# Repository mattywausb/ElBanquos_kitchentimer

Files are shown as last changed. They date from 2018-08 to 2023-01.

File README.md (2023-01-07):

# ElBanquos Kitchentimer
An Arduino based "multichannel" Timer, optimized for tracking times during food preparation

# Motivation
When preparing food I have to keep track of multiple countdowns. Even though one could solve this by putting multiple cheap timers on the fridge door or use a smartphone app there are some benefits with an extra device.
* better control when setting the time (cheap timers normally just go up, higher settings are a pain, correcting after start is nearly impossible)
* no need to clean all your fingers to change a timer
* Smartphone normally switches of the screen, so you can't see the current state (or they keep screen on and drain smart phone battery for neraly nothing)
* Smartphone somtimes is needed to check recepies, problem solutions or communicating (is that so?). Again you cannot see the current state of the timers just by looking at the device

# Features
* Track up to 4 timers (Well... limited by the number of display and interaction elements, you can extend this, with little modification)
* Main display mode shows all timers (no need to push a button to see the timers)
* wide range of intervals (1 second to 6 days (and thats only a coded limit) )
* Interval presets for your major use cases
* Assistence to set timer in relation to other timer
* Identity of alarming timer is "coded" in alarm melody

## Easy and intuitive 2 finger operations
* Set and start timer
* Size of dial steps adapts to total interval (there is normally no need to scroll over every second, when the interval is more than 5 minutes)
* Acknowledge alarm
* Change an alreday running timer (necessary when something irregular happened in the cooking process)
* put timer on hold
* cancel timer
* check the original time, the timer started from
* measure time since timer is over
  
# What you will find in the repository
* Arduino sketch for the timer
* Fritzing sketch for the hardware used in the implementation
* Manuals
    * [English](https://mattywausb.github.io/ElBanquos_kitchentimer/docs/manual-en.html)
    * [German](https://mattywausb.github.io/ElBanquos_kitchentimer/docs/manual-de.html)

# What you also need
* my extended version of the arduino "ledcontrol" library: https://github.com/mattywausb/LedControl

# How can you use it
* You can just build the timer by yourself using the same parts (check the fritzing sketch)
* The module architecture allows you to excahnge the elements of the interface
  * Display type
  * Kind of buttons input methods
  * sound generation
  
# Video
* [Demo and quick guide video](https://youtu.be/dwYkCimMoDo)

# More details 
* [check the wiki] (https://github.com/mattywausb/ElBanquos_kitchentimer/wiki)

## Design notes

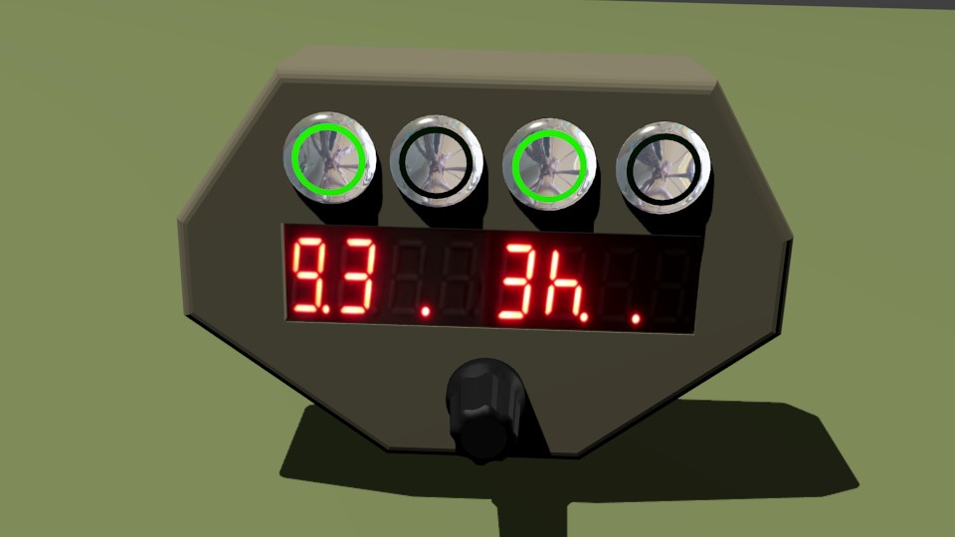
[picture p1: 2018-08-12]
docs/vision_1.jpg

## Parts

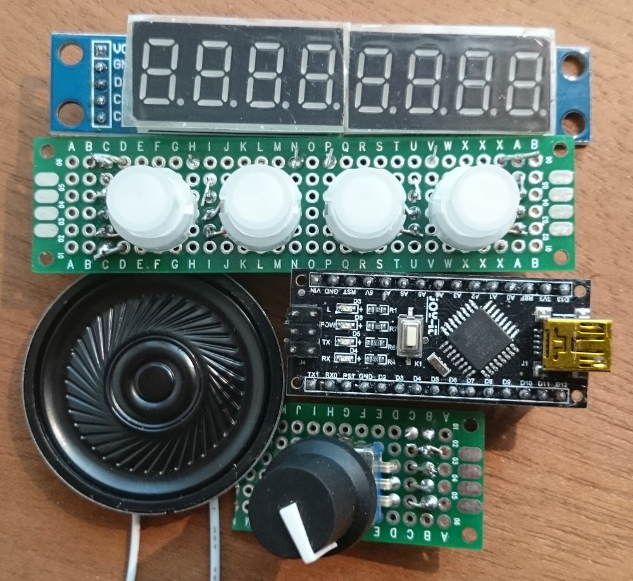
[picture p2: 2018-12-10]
docs/build_pictures/01_components_front.jpg

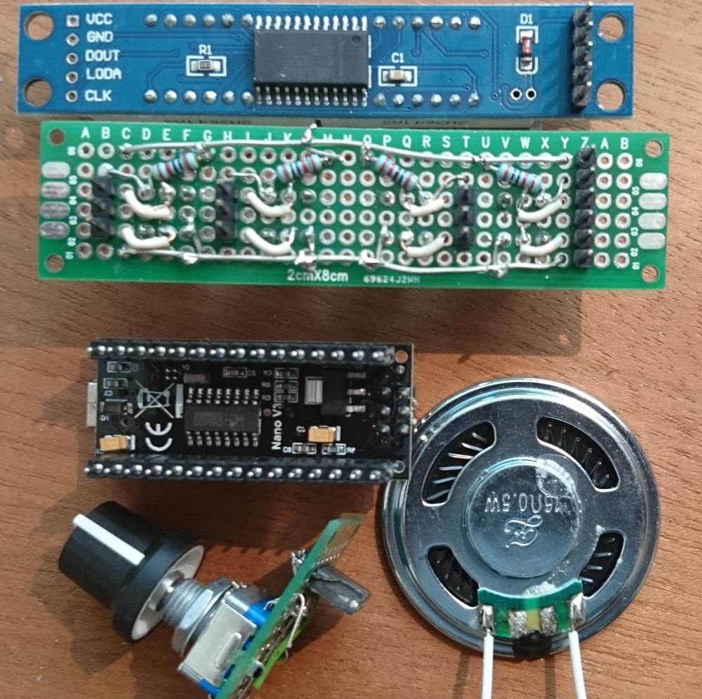
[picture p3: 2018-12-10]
docs/build_pictures/02_components_rear.jpg

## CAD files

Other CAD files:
blender/model_mk2.blend

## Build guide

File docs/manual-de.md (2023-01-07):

[Back to mainpage](https://mattywausb.github.io/ElBanquos_kitchentimer)
___
# Elemente und Aufbau des Gerätes
Elbanquos Kitchentimer besteht aus folgenden Elementen:
* 8 stellige Ziffenanzeige, je nach Modus 2 Ziffern zu jedem Timer oder für 8 stelliges Informationen 
* Je Timer ein dedizierter Taster
* Je Timer eine Timer-LED (eingebaut in den Taster)
* Zentraler Drehregler mit Tastfunktion

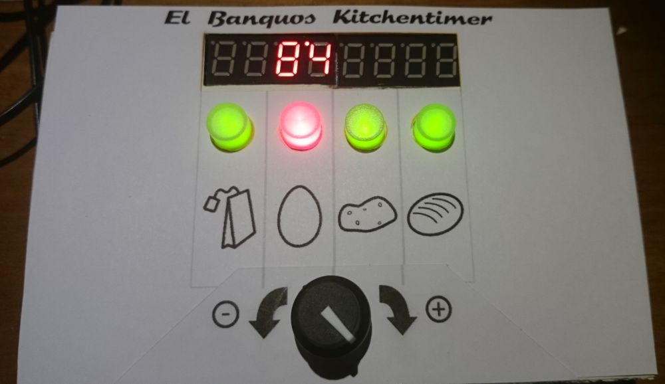
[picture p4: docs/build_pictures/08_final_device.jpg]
The timer


# Kurzanleitung
Um einen Timer zu **aktivieren** ist folgendes zu tun
* Mit dem  ***Drehregler*** die gewünschte Zeit einstellen (beginnt bei **10 Minuten**)
* Taster eines inaktiven (LED Grün oder aus) Timers drücken ->  Der Timer startet. Der Timer Taster leuchtet dauerhaft rot.

Um einen **Timer mit einer voreingestellte Zeit** zu aktivieren:
* ***Taster*** des gewünschten Timers ***drücken*** -> die Vorgabezeit des jeweiligen Timers wird angezeigt und der Taster blinkt grün
* Mit dem ***Drehregler*** bei Bedarf die Zeit anpassen
* Um die Zeit ggf. auf einem anderen freien Timer zu legen, ***anderen Timer Taster drücken***
* ***Taster des Timers oder den Drehregler drücken*** -> Der Timer startet. Der Timer Taster leuchtet dauerhaft rot.

Um bei einem aktiven Timer die **verbleibende Zeit exakt abzulesen**:
* ***Taster des gewünschten Timers drücken*** -> Zeit wird in allen Details angezeigt
* ***Taster des Timers erneut drücken*** -> es werden wieder alle Timer angezeigt

Um die Zeit eines bereits **laufenden Timers zu ändern**:
* ***Taster des gewünschten Timers drücken*** -> Zeit wird in allen Details angezeigt
* Mit dem ***Drehregler*** die Zeit anpassen
* ***Taster des Timers*** drücken ***oder den Drehregler kurz drücken***

Ist ein **Timer abgelaufen** ertönt ein Signalton und Taster und Anzeige des Timers blinken sehr schnell.
* **Alarm beenden** Durch ***drücken des blinkenden Tasters***
* Alternativ schaltet sich der Alarm nach 45 Sekunden von selbst ab sofern nicht ein weitere Timer abläuft. 

Im **Nachlaufmodus** zählt der Timer die Zeit, die mit Beginn des Alarms verstrichen ist. Der Timer-Taster ist dunkel und im Display wird die seit dem Alarm verstrichene Zeit abwechselnd mit "\_ \_" angezeigt. Ab 2 Minuten wird nur noch "\_ \_" angezeigt. Die **seit dem Alarm verstrichende Zeit** kann durch ***Drücken des Tasters*** abgerufen werden. 

Um einen Timer (egal ob abgelaufen oder aktiv) zu **deaktivieren** ist folgendes zu tun:
* ***Taster des Timers 5 Sekunden halten*** -> Für den Timer wird kurz "OF angezeigt und der Timer ist danach wieder inaktiv (grün). Ein abgelaufender Timer deaktiviert sich selbst nach der Hälfte seiner ursprünglichen Laufzeit. (Frühestens allerding nach 3 Minuten und spätestens nach 90 Minuten)

Weitere Funktionen werden im Abschnitt "Die Fuktionen im einzelnen" beschrieben.

# Die Zeitanzeige im Detail
## Hauptanzeige (Kompakte Darstellung aller Timer parallel)
Auf der Hauptanzeige werden die Zeiten von allen Timern parallel nebeneinander dargestellt. Für jeden Timer sind zwei Ziffern der Anzeige passend zur Position des Tasters und der Timer-Led vorgesehen. Die Darstellung ist wie folgt:
* **Zeitinformation**
    * "zz" (Zwei Ziffern, ohne Punkt, sekündlich abwärtslaufend) - verbleibende Sekunden zz bis zum Alarm 
    * "y'z" (Zwei Ziffern, mit einem Punkt oben getrennt) - mehr als 60 Sekunden Zeit: Vor dem Punkt : Verbleibende Minuten y, Nach dem Punk verbeibende 10 Sekundenschritte
    * "'yy" (Zwei Ziffern, denen ein Punkt vorangestellt ist) - mehr als 10 Minuten Zeit: Verbleibende Minuten
    * "xh" - (eine Ziffer gefolgt von einem kleinen h und einem Punkt) -  mehr als 1 Stunde Zeit: Verbleibende Stunden x
    * "Hx'" - (Ein großes H gefolgt von einer Ziffer und einem Punkt) -  mehr als 10 Stunden Zeit: Verbleibende 10 Stundenschritte
    * "vd'" - (eine Ziffer gefolgt von einem d und einem Punkt) -  mehr als 24 Stunden Zeit: verbleibende Tage
* **Statusinformation**
	* keine Anzeige - Der Timer ist nicht aktiv
    * "\_ \_"  = Der Timer ist im Nachlaufmodus
    * "\_ \_"  Wechselnd zu einer der Zeitinformation = Der Alarm ist keine 2 Minuten her
    * "°_" und "_°" = Timer Alarm in schnellem Wechsel mit einer Zeitinformation
	* "P" vor der Zeitanzeige: Die Zeiteinstellung erfolgt in Relation zu einem Partnertimer
	* "A" vor der Zeitanzeige: Es wird die ursprünglich eingestellte Zeit des Timers angezeigt

Beispiele:
* 12 = 12 Sekunden 
* 5'3 = 5 Minuten und 30-39 Sekunden
* 24' = 24 Minuten
* 2h  = Zwischen 2 Stunden und 2 Stunden, 59 Minuten, 59 Sekunden
* 4d  = Mindestenst 4 Tage, weniger als 5 Tage

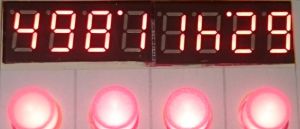
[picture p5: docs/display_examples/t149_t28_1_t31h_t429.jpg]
Example


* Timer 1 hat noch 49 Sekunden
* Timer 2 hat noch 8 Minuten und mindestens 10 Sekunden
* Timer 3 hat noch mehr als 1 Stunde (aber weniger als 2)
* Timer 4 hat noch 29 Minuten
 
## Anzeige einer einzelnen Zeit
Bei der Auswahl eines Timers und für die Einstellung der Zeit gibt zwei Formate der Darstellung:

* xx**h**'yy'zz - Für alle Werte unter 24 Stunden wird die Stunde x, die Minuten yy und die Sekunden zz angezeigt
* v**d**xx**h**'yy - Wert größer 24 Stunden werden mit der Anzahl Tage v, die Stunden xx und Minuten yy angezeigt.

Beispiel:
Example

## Information durch die LED im Timer-Taster
* LED **grün** durchgehend: Der Timer ist ***inaktiv*** 
* LED **blinkt regelmäßig**: Der Timer ist ***ausgewählt*** für die Detailsanzeige oder Zeiteinstellung. Sollten zwei Timer blinken, so wird der grün blinkende Timer in Relation zu dem rot blinkenden eingestellt. 
* LED **rot** durchgehend: Der Timer ***läuft***
* LED **rot schnell blinkend** mit kurzen Pausen: Der Timer hat einen ***Alarm***
* LED **rot** erlischt kurz im **"Herzschlagryhtmus"**: Der Timer ist im ***Pausemodus***
* LED **aus**: Der Alarm für den Timer wurde beendet und der Timer ist im ***Nachlaufmodus***. Er steht für einen neuen Start zur Verfügung. 

# Die Funktionen im Einzelnen
Alle Funktionen werden hier ausgehend von der Hauptanzeige(siehe oben) beschrieben. Diese erreicht man im Zweifelsfall immer durch kurzes Warten (15 Sekunden).

## Timer einstellen und starten
Anmerkung vorab: Um auch große Zeitintervalle effizient erreichen zu können wächst der Zeitabstand pro Schritt des Drehregles mit der insgesamt gewählten Zeit. Dadurch kann nicht für jedes Intervall eine sekundengenaue Einstellung erfolgen (Weitere Details dazu im Anhang "Stufung der Einstellintervalle"). 

### Per Drehregler
* Mit dem Drehregler eine Zeit einstellen (Die erste Bewegung des Reglers setzt diese auf 10 Minuten).
* Taster eines nicht laufenden Timers (_LED grün oder aus_) drücken -> Der Timer wird gestartet.

Solange noch kein Timer ausgewählt wurde, kann die Eingabe durch langes Drücken des Drehreglers abgebrochen werden. 
Die Eingabe wird ebenfalls abgebrochen, wenn man 15 Sekunden lang keine Bedienhandlung vornimmt.

### Direkte Zeitvorwahl je Timer
* Taster eines deaktivierten(LED ist grün) Timers drücken -> die für den Timer vorprogrammierte Vorschlagszeit erscheint,Timer-Led blinkt
* Mit dem Drehregler die Zeit anpassen
* Timer starten indem man auf den Drehregler drückt _oder_ erneut die Taste des Timers betätigt
* Option: Drückt man stattdessen die Taste eines anderen inaktiven Timers, wird auf diesen als Ziel für die eingestellte Zeit umgeschaltet. Ein erneuter Druck auf dessen Taster oder den Drehknopf startet diesen Timer. Der ursprüngich ausgewählte Timer bleibt dann unberührt.

Die Eingabe durch langes drücken des Drehreglers abgebrochen werden. 
Die Eingabe wird ebenfalls abgebrochen, wenn man 15 Sekunden keine Bedienhandlung vornimmt.

### Zeitvorwahl mit abgelaufenem Timer
* Taster eines nachlaufenden(LED ist aus) Timers drücken -> die Nachlaufzeit des Timers wird angezeigt,Timer-Led blinkt
* Die erste Bewegung des Drehreglers stellt die Zeit auf die vorprogrammierte Vorschlagszeit
* Danach kann die Zeit weiter angepasst werden
* Timer starten indem man auf den Drehregler drückt _oder_ erneut die Taste des Timers betätigt
* Option:Drückt man stattdessen die Taste eines anderen inaktiven Timers, wird auf diesen als Ziel für die eingestellte Zeit umgeschaltet. Ein erneuter Druck auf dessen Taster oder den Drehknopf startet diesen Timer. Der ursprüngich ausgewählte Timer bleibt dann unberührt.

### Zeitabstand zu laufendem Timer
Möchte man einen Timer stellen, der eine definierte Zeit __vor__ einem schon laufenden Timer abläuft, ist wie folgt zu verfahren:
* Taster des aktiven Timers, für zu dem man einen Abstand festlegen will drücken und halten. 
* zusätzlich Taster des inaktiven Timers drücken, der vor dem schon aktiven Timer ablaufen soll -> Der Taster des aktiven Timers blinkt rot, der Taster des einzustellenden Tasters blinkt grün. In der Zeitanzeige wird die Hälfte der Restzeit des aktiven Timers vorgeschlagen. Mit einem "P" in der Anzeige wird angezeigt, dass der "Partnermodus" aktiviert ist
* Mit dem Drehregler die Restzeit einstellen, die der aktive Timer haben soll, wenn der jetzt eingestellte Timer abläuft.
* Den zweiten Timer starten, indem man den Drehregler drückt oder den Taster des zweiten Timers->Der zweiten Timer erhält dabei eine Laufzeit, die in Relation zu dem partner mit dem eingestellten Abstand abläuft. 
Sollte die Zeit des Ursprungstimers nicht mehr ausreichen, um die gewünschte Zeit zu realisieren, wird der Timer nicht gestartet. Stattdessen wird kurz ein Fehler angezeigt und danach die Ursprungtimer wieder angezeigt. So kann bei Bedarf, dessen Zeit veändert werden, oder das Prozedere für einen zweiten Timer erneut begonnen werden.

Die Timer sind danach nicht weiter verkoppelt, d.h. wenn der erste Timer pausiert oder verändert wird, hat das keine Auswirkung auf den zweiten Timer. Der ürsprünglich gewünschte Zeitabstand ist dann nicht mehr gegeben.

## Timer Restzeit anzeigen
Um die exakte Restzeit eines Timers anzuzeigen:
* Taster des gewünschten aktiven Timers drücken -> Ausführliche Restzeit (oder die Zeit seit dessen Ablauf) wird angezeigt. Die Timer-Led blinkt.
* Durch erneutes Drücken des Tasters wird wieder die Hauptanzeige angezeigt
* Alternativ: Durch Drücken des Tasters eines anderes aktiven Timers wird zu dessen Anzeige umgeschaltet.

## Timer pausieren
Um einen Timer anzuhalten:
* Taster des gewünschten laufenden Timers drücken -> Ausführliche Restzeit wird angezeigt. Die Timer-Led blinkt.
* Den Drehregler kurz drücken -> Auf der Position des Timers wird kurz "PA" angezeigt. Danach erscheint die Hauptanzeige und die Ziffern des Timers, sowie dessen Timer-Led blinken mit einem langsamen "Herzschlagryhtmus"

## Pausierten Timer wieder aktivieren
Um einen pausierten Timer wieder zu aktivieren:
* Taster des pausierten Timers drücken -> Ausführliche Restzeit  wird angezeigt. Die Timer-Led blinkt.
* Den Drehregler kurz drücken -> Auf der Positin des Timers wird kurz "Go" angzeigt. Danach der erscheint die Hauptanzeige und der Timer wird wieder durchgehend angezeigt.

## Timer Restzeit ändern
Um die Restzeit eines Timers anzupassen:
* Taster des gewünschten laufenden Timers drücken -> Ausführliche Restzeit (oder die Zeit seit dessen Ablauf) wird angezeigt. Die Timer-Led blinkt.
* Mit dem Drehregler die Zeit entsprechend anpassen 
* Neue Zeit mit Druck auf Drehregler oder den Taster des Timers bestätigen-> Hauptanzeige mit der geänderten Zeit wird angezeigt. War der Timer vorher pausiert, ist er jetzt wieder aktiv 
* Alternativ: Änderung durch Drücken und halten des Drehreglers verwerfen

## Timer Startzeit anzeigen
Um die ursprüngliche Startzeit des Timers anzuzeigen:
* Taster des gewünschten aktiven Timers drücken -> Ausführliche Restzeit (oder die Zeit seit nach dessen Ablauf) wird angezeigt. Die Timer-Led blinkt.
* Drehregler drücken und halten -> Die ursprüngliche Startzeit wird angezeigt bis man den Drehregler wieder loslässt
* Taster des Timers erneut drücken um wieder in die Anzeige aller Timer zu kommen oder 15 Sekunden abwarten

## Timer Alarm bestätigen
Wenn ein Timer im Alarmmodus ist, kann dieser deaktiviert werden in dem man
* den Taster des Timers einmal betätigt
Dies funktioniert in jeder Bediensituation.

## Timer deaktivieren
Um einen Timer vorzeitig abzuschalten, oder nach Ablauf der Zeit dessen Nachlaufmessung zu beenden:
* Taster des Timer drücken und für 5 Sekunden halten -> Auf der Positin des Timers wird kurz "OF" angzeigt. Danach der erscheint die Hauptanzeige und der Timer ist deaktiviert.

Ein Timer deaktiviert sich automatisch nach einer Nachlaufzeit, die dem doppelten seiner Start entspricht +45 Sekunden, maximal aber 90 Minuten . Diese Regel entspringt dem Gedanken, dass spätestens nach der doppelt eingestellten Zeit die zu messende Aktivität entweder komplett erledigt oder aus dem Ruder gelaufen ist. 

## Timer kopieren
Es ist möglich von einem laufenden Timer die Zeit zu "Kopieren".
* Taster des gewünschten laufenden Timers drücken von dem die Zeit kopiert werden soll -> Ausführliche Restzeit (oder die Zeit seit nach dessen Ablauf) wird angezeigt. Die Timer-Led blinkt.
* Mit dem Drehknopf eine (ggf. auch sehr kleine) Änderung der Zeit vornehmen
* Taster des "Ziel"-Timers, auf den der Wert kopiert werden soll drücken (muss ein freier Timer sein) ->Die Timer-Led des anvisierten Timers blinkt.
* Taster des "Ziel"-Timers erneut drücken -> Der Timer startet mit der entsprechenden Zeit. Der Timer von dem die Zeit kopiert wurde, verbleibt in seinem vorigen Zustand.

# Der "Melodiecode" im Alarmton
Die Melodie des Alarmtons richtet sich nach dem alarmgebenden  Timer wie folgt:
* Grundmelodie sind 5 gleiche Töne gefolgt von einer 3 Noten langen Pause
* Der zweite bis vierte Ton der 5 Töne wird je nach alarmieredem Timer anhgehoben. Die Anzahl der Töne vor dem angehobenen Ton gibt die Position des Timers auf dem Bedienfeld an. Sind mehrere Timer im Alarmzustand werden entsprechend alle zugehörigen Töne angehoben.

# Unterschiedliche Genauigkeitsstufung 
Da bei der Zeitmessung für größere Intervalle eine geringere Genauigkeit akzeptabel ist (zumindest in einer normalen Küche) wird die Einstellgenauigkeit gröber mit der Größe der Gesamtzeit. So bleibt die Anzahl der notwendigen Umdrehungen des Drehknopfes auch für sehr große Intervalle überschaubar (Hallo Sauerteigbrotbäcker und Soßenspezialköche).

    Zeit   Genauikeit
    <30 s    1 s
    <2 min   5 s
    <5 min   10 s
    <15 min  15 s
    <30 min  30 s
    <1 h     1 min
    <3 h     10 min
    <24 h    15 min
    <48 h    30 min
    >48 h     1 h

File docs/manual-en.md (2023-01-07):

[Back to mainpage](https://mattywausb.github.io/ElBanquos_kitchentimer)
___
# Description of the device
Elbanquos Kitchentimer consist of the following elements:
* 8 digit display, using 2 digits for every timer or all digits for showing detailled time information
* one button for every timer
* one state led for every timer integrated in the button
* one general dial to adjust time values (can also be pushed)

The timer

# Quick start
To **activate** a timer, starting with a preset of **10 Minutes**:
* ***turn dial*** to adjust the time
* ***press timer button*** of an inactive timer(green or off) ->  the timer starts. Remaining time is displayed with the two digits for the timer. The timer led will be lit red continuosly.

To **activate** a timer, starting with a **timer specific preset time** :
* ***press timer button*** of your target timer (must be green or off)-> timer specific preset time will be selected, timer led will blink green
* ***turn dial*** to adapt time as needed
* ***press dial*** or the timer button ->  the timer starts. Remaining time is displayed with the two digits for the timer. The timer led will be lit red continuosly.
You can change the timer by pressing another valid timer button (Green or off) before starting.

To **check remaining time** in detail:
* ***press timer button*** of the active timer -> time will be displayed in full detail
* ***press timer button*** of the timer again -> switch back to normal display

To **adjust an active timer**:
* ***press timer button*** of the active timer -> time will be displayed in full detail
* ***turn the dial*** to change the time
* ***press dial*** or timer button ->  the timer starts with new time

**When reaching 0 seconds** the timer will trigger the alarm and blink in a rapid pattern.
By ***pressing the timer button*** you ackknowledge the alarm. This will also be done automatically after 45 seconds. 

The timer will continue to count the time after the alarm. The timer led will be off now. The digits of the timer will show "\_ \_" alternating to the counted time for 2 minutes. After 2 minutes, the digits will display "\_ \_" continuosly. To see the **time since the alarm**, ***press the timer button***.

To **cancel** a running the timer completely: 
* ***press and hold the timer button for 5 seconds*** -> The display will show "OF" at the timers digits for 2 seconds, and the timer is completly cancled. This will also happen automaticlly after half of the time, the timer was measuring (but at least after 3 minutes and definitly after 90 Minutes).

# Understanding the display information
## Compact display (Main display)
The compact display, shows all timer states in paralell. Every timer is represented by 2 digits of the display as follows:
* Time information
    * "zz" (two numbers, no decimal point, counting down) - remaining seconds zz  
    * "y'z" (two numbers, separated with a dot on the top) - above 60 seconds: first digit - y minutes remaining, second digit - z 10 second steps remaining
    * "'yy" (two numbers, preceded by a dot in the top) - above 10 minutes: remaining minutes
    * "xh" - (one number followed by the letter "h") - above 1 hour: remaining hours x
    * "Hx." - (letter "H" followed by number)- above 10 hours: remaining 10 hour steps
    * "vd." - (a number followed by the letter "d") - above 24 hours: remaining days 
* State information
    * empty digits - timer is not active at all
    * "\_ \_" - timer is after alarm time
    * "\_ \_" alternating with time display - timer is less then 2 minutes after alarm time
    * "°_" or "_°" - timer has alarm
	* "P" in front of the detailed time: You are currently choosing a time differential in relation to a partner timer
	* "A" in front of the detailed time: The inital start time of the timer is displayed

Example:

Example

* Timer 1: 49 = 49 seconds 
* Timer 2: 8'1 = 8 minutes and 10-19 seconds
* Timer 3: 1h = between 1 hour and 2 hours 
* Timer 4: '29 = 29 minutes
 
## Detailed display
The detailed display is used when selecting the time or when showing detailed information for a timer. 
There are two formats:

* xx**h**'yy'zz - below 24 hours: x hours, yy minutes and zz seconds
* v**d**xx**h**'yy - above 24 hours: v days, xx hours and yy minutes.

Example:

Example

## Meaning of the timer led
* LED **green** continuously : The timer is ***deactivated**
* LED **blinks**: Der timer is ***selected*** in the main display and might get adjusted. If two timers are blinking, the blinking green one is modified in relation to the blinking red one.
* LED **red** continuously : Timer is ***running*** 
* LED **red blinking fast with short pauses** : Timer is on ***alert***
* LED **red blinks a heart beat rhythm**: timer is ***paused***
* LED **off** continuously: The timer is over due with a deactivated alarm. Timer can to be used for a new time setting. 

# Detailied operation instructions
(to be done in english. Check [german version](https://mattywausb.github.io/ElBanquos_kitchentimer/docs/manual-de.html) for "inspiration")

Just one essential Operation is already translated here:
## Relational time setting
If you want to set a timer to end at a specific time before another timer, you can use the following assistence feature:
* Press and hold the button of the already running timer you want to use as reference
* Press the button of a not active timer, you want to use -> The active timer will blink red and the target timer will blink green. Half of the current time of the activte timer is used as a proposal for the interval. A "P" in the display indicated, you are now in the "partner mode"
* With the dial, you can adjust the time the timer will be done before the reference timer
* By pressing the dial or the green blinking timer button, you will start the second timer. The interval of the timer will be calculated in relation to the reference timer, according to the time you have defined.

Remark 1: If you dial in a time, that is bigger then the remaining time of the reference timer, the starting will trigger a short error display and the timer is not started. Instead the reference timer will be displayed again.

Remark 2: This ist only a assistence to set a timer. After starting the second timer, the relation to its reference is not kept. Changing or pausing the former reference timer will have no impact on the second timer and the difference between both timers will be changed. Nevertheless you can recover it by canceling the second timer and repeat the relational setting

# The "Melody code" of the alarm sound

The alarm sound incorporates a melody code, to allow the recognotion, wich timer is calling.
* The base melody consist of 8 bars, each playing 5 8th notes followed by a quater and an 8th pause
* every bar has a constant note, that will be shifted up depeding on the timer that has an alarm
* by counting the notes before the shifted note you get the number of the timer

Example: 
* ".'..."  = Timer 1 has an alarm
* "...'." = Timer 3 has an alarm
* ".'..'" = Timer 1 and 4 hav an alarm

# Changing precision of the dial
The timer ist changing the granularity of the dial steps inrelation to the current interval. This allows to reach  a wide amount of time with less turning.
This behaviour takes into account, that for food preparation, it is normally not necessary to be absolutly precise, especially for long intervals.  
The following table explains the granularty steps used;

    Time   Granularity
    <30 s    1 s
    <2 min   5 s
    <5 min   10 s
    <15 min  15 s
    <30 min  30 s
    <1 h     1 min
    <3 h     10 min
    <24 h    15 min
    <48 h    30 min
    >48 h     1 h

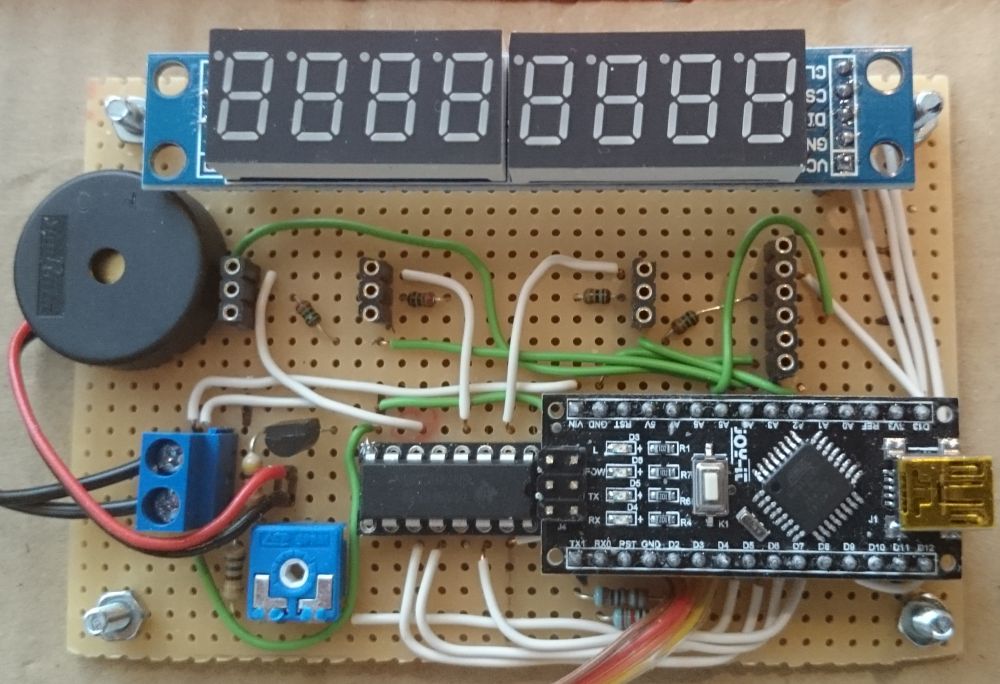
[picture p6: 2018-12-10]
docs/build_pictures/07_assembled.jpg

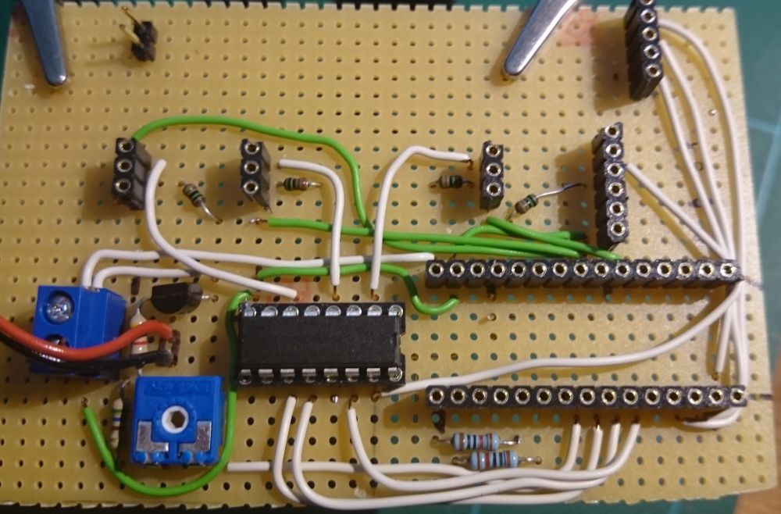
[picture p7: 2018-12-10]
docs/build_pictures/04_pcb_front.jpg

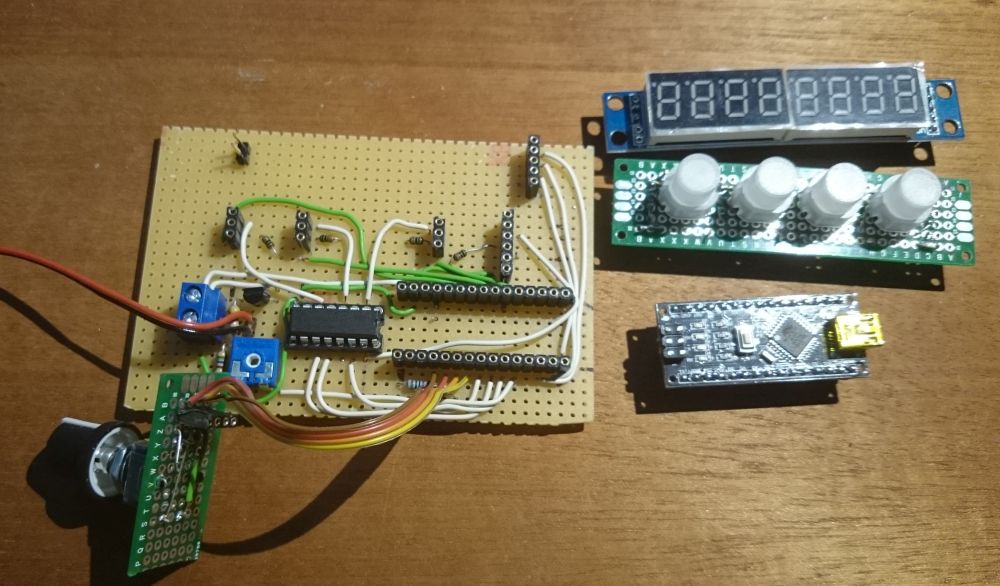
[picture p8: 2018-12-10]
docs/build_pictures/06_disassembled.jpg

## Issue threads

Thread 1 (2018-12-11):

"A" indikator gets not removed when switching back to detail display

mattywausb, 2018-12-11:
After showing the inital time, the "A" letter in the first digit stays, even though the running time is shown in detail again.
The letter is removed when switching back to the main display mode.

mattywausb, 2019-09-22:
Fixed

Closed 2019-09-22.

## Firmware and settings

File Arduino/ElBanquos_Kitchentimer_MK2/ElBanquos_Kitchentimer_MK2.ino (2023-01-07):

#include <LedControl.h>


#include "mainSettings.h"
#include "kitchenTimer.h"   // Class declaration

#ifdef TRACE_ON
#define TRACE_MODE 
#define TRACE_MAIN_EVENTS
//#define DEBUG_SCALE_TABLE 
#endif

#define DEFAULT_INTERVAL 600   // 10 Minutes
#define TIMER_MAX_INTERVAL 603800  // Seconds of 7 days
#define CONTROL_VALUE_MAX  convertTimeToControlvalue(TIMER_MAX_INTERVAL)
#define DEFAULT_INTERVAL_UP  600   // 10 Minutes as start value when turning upwards 
#define DEFAULT_INTERVAL_DN  600   // 10 Minutes as start value when turning downwards
#define UI_FALLBACK_INTERVAL 10   // seconds, ui will fall back to idle wihtout interaction
#define PRESS_DURATION_FOR_RESET 3000  // milliseconds you must hold select to disable a timer
#define PRESS_DURATION_SHORT 500  // milliseconds while a press counts as short 
#define ALERT_DURATION 45 // Seconds the alert will go without manual ackknowledgement
#define MAX_OVER_TIME 5400 // Seconds the over time mode will be kept befor complet disabling the timer
#define MIN_OVER_TIME 180 // Seconds the over time mode will be kept at least

const long timer_interval_preset[]={1800,1200,375,180}; // 30 min, 20 min, 6'15 min, 3 min (order is right to left)


enum UI_MODES {
  IDLE_MODE, 
  PRESELECT_MODE,
  DISPLAY_MODE,
  SET_MODE
};
UI_MODES ui_mode = IDLE_MODE; 


byte ui_focussed_timer_index=0;  // this  is only relevant in DISPLAY and SET mode and will determined before entering these
byte ui_partner_timer_index=INDEX_FOR_UNDEFINED_TIMER;  // index of the timer, we refer when dialing in a delta time set

bool ui_button_press_from_previous_mode=false;

KitchenTimer myKitchenTimerList[TIMER_COUNT];

/* *************** IDLE_MODE ***************** 
*/
void enter_IDLE_MODE(){
  #ifdef TRACE_MODE
    Serial.println(F("#IDLE"));
  #endif
  ui_mode=IDLE_MODE;
  output_clearDisplay();
  input_IgnoreUntilRelease();
  ui_partner_timer_index=INDEX_FOR_UNDEFINED_TIMER;
}

void process_IDLE_MODE()
{
  KitchenTimer *focussed_timer;

  /* Timer Buttons */
  for(ui_focussed_timer_index=0;ui_focussed_timer_index<TIMER_COUNT;ui_focussed_timer_index++)
  {  
    focussed_timer=&myKitchenTimerList[ui_focussed_timer_index];
    if(input_timerButtonGotPressed(ui_focussed_timer_index) )
    {
      if(focussed_timer->hasAlert()){
        focussed_timer->acknowledgeAlert(); 
        #ifdef TRACE_MAIN_EVENTS
            Serial.println(F("TRACE_MAIN_EVENTS>alert acknowledged"));
        #endif

      } else {
        if(focussed_timer->isDisabled()) enter_SET_MODE( timer_interval_preset[ui_focussed_timer_index] );  
        else enter_DISPLAY_MODE();
        return;      
      }
    } 
  }

  /* Encoder Movement */
  if(input_hasEncoderChangeEvent()) 
  {
    enter_PRESELECT_MODE();
    return;
  }

  /* Automated acknowledgement */
  for(int i=0;i<TIMER_COUNT;i++)
  {
    if(myKitchenTimerList[i].hasAlert()
       && (myKitchenTimerList[i].getTimeLeft()< -ALERT_DURATION) ) // TODO: Make this longer, when not in IDLE
           {myKitchenTimerList[i].acknowledgeAlert();
           #ifdef TRACE_MAIN_EVENTS
            Serial.println(F("TRACE_MAIN_EVENTS>alert exceeded max duration"));
          #endif
           }
  }

  /* Automated disabling after twice of runtime */
  for(int i=0;i<TIMER_COUNT;i++)
  {
    if(myKitchenTimerList[i].isOver() && -myKitchenTimerList[i].getTimeLeft()>MIN_OVER_TIME)
    {
      if (((-myKitchenTimerList[i].getTimeLeft())>MAX_OVER_TIME)
      || (-myKitchenTimerList[i].getTimeLeft()>(myKitchenTimerList[i].getLastSetTime()*2))) myKitchenTimerList[i].disable();
    }
  }

  output_renderIdleScene(myKitchenTimerList);
}


/* *************** PRESELECT_MODE ***************** 
*/
void enter_PRESELECT_MODE(){
  #ifdef TRACE_MODE
    Serial.println(F("#PRESELECT_MODE"));
  #endif
    ui_mode=PRESELECT_MODE;
    input_setEncoderRange(0,CONTROL_VALUE_MAX,1,false);  
    input_setEncoderValue(convertTimeToControlvalue(DEFAULT_INTERVAL));
    output_clearDisplay();
    output_renderPreselectScene(myKitchenTimerList,convertControlvalueToTime(input_getEncoderValue()));    
}

void process_PRESELECT_MODE()
{
  KitchenTimer *focussed_timer;

   /* UI Fallback, after brief time of no interaction */
   if(input_getSecondsSinceLastEvent()>UI_FALLBACK_INTERVAL) 
   {
     enter_IDLE_MODE();
     return;    
   }

  /* Start timer by hitting timer button */
  for(ui_focussed_timer_index=0;ui_focussed_timer_index<TIMER_COUNT;ui_focussed_timer_index++)
  {  
    focussed_timer=&myKitchenTimerList[ui_focussed_timer_index];
    if(input_timerButtonGotReleased(ui_focussed_timer_index) )
    {
      if(focussed_timer->hasAlert()){
        focussed_timer->acknowledgeAlert();
        #ifdef TRACE_MAIN_EVENTS
            Serial.println(F("TRACE_MAIN_EVENTS>alert acknowledged"));
        #endif

      } else {
        if(focussed_timer->isOver() ||
           focussed_timer->isDisabled())  // timer is free to use
           {
              focussed_timer->setInterval(convertControlvalueToTime(input_getEncoderValue()));
              focussed_timer->startCounting();
              output_startTimerSequence(myKitchenTimerList,ui_focussed_timer_index);
              #ifdef TRACE_MAIN_EVENTS
                  Serial.print(F("TRACE_MAIN_EVENTS>Start Timer "));Serial.print(ui_focussed_timer_index);
                  Serial.print(F("Interval is "));Serial.println(focussed_timer->getLastStartTime());
              #endif
              enter_IDLE_MODE();
              return;
           } else {
            output_blockedSequence(myKitchenTimerList,ui_focussed_timer_index); 
           }                        
      }
      return;  
    } 
  }

  /* Dial Button long */
  if( input_dialIsPressed() && input_getCurrentPressDuration()>PRESS_DURATION_SHORT)
  {
    enter_IDLE_MODE(); 
    return;
  }

  
  output_renderPreselectScene(myKitchenTimerList,convertControlvalueToTime(input_getEncoderValue()));   
}


/* *************** DISPLAY_MODE ***************** 
*/
void enter_DISPLAY_MODE(){
  #ifdef TRACE_MODE
    Serial.println(F("#DISPLAY_MODE"));
    Serial.print(F("ui_focussed_timer_index="));Serial.println(ui_focussed_timer_index);
    Serial.print(F("time left: "));Serial.println(myKitchenTimerList[ui_focussed_timer_index].getTimeLeft());
  #endif

  input_setEncoderRange(-200,200,1,false);   // set encoder to track an initial movement 
  input_setEncoderValue(0);  
    
  ui_mode=DISPLAY_MODE;
  ui_button_press_from_previous_mode=true;
  output_clearAllSequence ();
  output_renderSetScene(myKitchenTimerList,myKitchenTimerList[ui_focussed_timer_index].getTimeLeft(),ui_focussed_timer_index,INDEX_FOR_UNDEFINED_TIMER);
}

void process_DISPLAY_MODE() {
 

   KitchenTimer *focussed_timer=&myKitchenTimerList[ui_focussed_timer_index];
   
   /* UI Fallback, after brief time of no interaction */
   if(input_getSecondsSinceLastEvent()>UI_FALLBACK_INTERVAL) 
   {
     enter_IDLE_MODE();
     return;    
   }

   /* Long press of current timer = Switch timer off */
   if( input_timerButtonIsPressed(ui_focussed_timer_index)
   && input_getCurrentPressDuration()>PRESS_DURATION_FOR_RESET)
   {
       focussed_timer->disable();
       output_resetSequence(myKitchenTimerList,ui_focussed_timer_index);
       enter_IDLE_MODE();
       return;       
   }

   /* Start partnered setting when current button is hold and another valid timer button got pressed */
  if( input_timerButtonIsPressed(ui_focussed_timer_index)) {
    for(byte other_timer_index=0;other_timer_index<TIMER_COUNT;other_timer_index++) {
      if(other_timer_index==ui_focussed_timer_index) continue;
      if(input_timerButtonGotPressed(other_timer_index) && 
        (myKitchenTimerList[other_timer_index].isOver() || myKitchenTimerList[other_timer_index].isDisabled()) ) { // Valid Target
          ui_partner_timer_index=ui_focussed_timer_index;
          ui_focussed_timer_index=other_timer_index;
          #ifdef TRACE_MAIN_EVENTS
                  Serial.println(F("TRACE_MAIN_EVENTS>Request for partnered setting "));
          #endif
          enter_SET_MODE( myKitchenTimerList[ui_partner_timer_index].getTimeLeft()/2 );
          return;
      }
    }
  }

   /* Catch and ignore the first release of the button, since it triggered the display mode  and should not trigger upcoming events */
   if( ui_button_press_from_previous_mode && !input_timerButtonIsPressed(ui_focussed_timer_index))
   {
    ui_button_press_from_previous_mode=false;
    return;
   }
   
   /* Got back to idle when focussed timer button was pressed short */
   if(input_timerButtonGotReleased(ui_focussed_timer_index)&& input_getCurrentPressDuration()<PRESS_DURATION_FOR_RESET ) {
     enter_IDLE_MODE();
     return;    
   } 

  /* Display last set time of timer when dial is pressed long */
   if( input_dialIsPressed() && input_getCurrentPressDuration()>PRESS_DURATION_SHORT)
   {
    output_renderSetScene_withLastTime(myKitchenTimerList,focussed_timer->getLastSetTime(),ui_focussed_timer_index); 
    return;
   }

  /* Display current time when dial is released again */
  if( input_dialGotReleased() && input_getLastPressDuration()>PRESS_DURATION_SHORT) {
      output_clearDisplay();
      return;  // Just to omit short button release reaction, Display will come up in next cycle
  } 

  /* pause/resume running timer with dial button short, go back to idle if timer is already over */
  if( input_dialGotReleased() )
  {
      
    if(focussed_timer->isOver())  
    {
      enter_IDLE_MODE();
      return;
     }

    if(focussed_timer->isRunning()) 
    {
      focussed_timer->stopCounting();
      output_holdSequence(myKitchenTimerList,ui_focussed_timer_index);
      enter_IDLE_MODE();
      return;   
    }
    
    if(focussed_timer->isOnHold()) 
    {
      focussed_timer->startCounting();      
      output_startTimerSequence(myKitchenTimerList,ui_focussed_timer_index);
      enter_IDLE_MODE();
      return;   
    } 
  }
  
   /* Ackowledge alert of any alerting timer or switch focus to other timer with timer buttons */
  for(int other_timer_index=0;other_timer_index<TIMER_COUNT;other_timer_index++)
  {
    if(other_timer_index==ui_focussed_timer_index) continue;
    
    if(input_timerButtonGotPressed(other_timer_index)) {
     if(myKitchenTimerList[other_timer_index].hasAlert()){
        myKitchenTimerList[other_timer_index].acknowledgeAlert(); 
        return;
     } else {  // Switch focus to other timer
        ui_focussed_timer_index=other_timer_index;  
        #ifdef TRACE_MODE
          Serial.print(F("TRACE_MAIN_EVENTS>switched to timer ")); Serial.print(ui_focussed_timer_index);
          Serial.print(F(" time left: "));Serial.println(myKitchenTimerList[ui_focussed_timer_index].getTimeLeft());
      #endif
        focussed_timer=&myKitchenTimerList[ui_focussed_timer_index];
                input_IgnoreUntilRelease();
        if(focussed_timer->isDisabled()) 
        {
          enter_IDLE_MODE();  
          return;
        }

     }
     } 
   }
  
  /* Switch to setting the current shown, when dial is turned  */
  
  if(input_hasEncoderChangeEvent()) {
    input_getEncoderValue(); // acknowledge the processing of the change to the input module
    if(focussed_timer->isRunning() || focussed_timer->isOnHold()) 
    {
      enter_SET_MODE(focussed_timer->getTimeLeft());    
      return ;             
    } else {  // there is no timer value we can start from o lets take the preset
      if(input_getEncoderValue()>0) enter_SET_MODE(timer_interval_preset[ui_focussed_timer_index]);
      else                          enter_SET_MODE(timer_interval_preset[ui_focussed_timer_index]);  // There might be a use of different values depending on the turning direction
      return;
    }
  }

  /* Provide output */
  output_renderSetScene(myKitchenTimerList,focussed_timer->getTimeLeft(),ui_focussed_timer_index,INDEX_FOR_UNDEFINED_TIMER);
  
}

/* *************** SET_MODE ***************** 
*/

void enter_SET_MODE(long preselected_time)
{
  #ifdef TRACE_MODE
    Serial.println(F("#SET_MODE"));
    Serial.print(F("preselected_time ="));Serial.println(preselected_time);
    Serial.print(F("ui_focussed_timer_index="));Serial.println(ui_focussed_timer_index);
    Serial.print(F("ui_partner_timer_index ="));Serial.println(ui_partner_timer_index);
  #endif
  ui_mode=SET_MODE;
  input_setEncoderRange(0,CONTROL_VALUE_MAX,1,false);   
  input_setEncoderValue(convertTimeToControlvalue(preselected_time));  
  output_clearAllSequence ();
  input_IgnoreUntilRelease();
}

void process_SET_MODE()
{
   
   KitchenTimer *focussed_timer=&myKitchenTimerList[ui_focussed_timer_index];
   
   /* UI Fallback, after brief time of no interaction */
   if(input_getSecondsSinceLastEvent()>UI_FALLBACK_INTERVAL) 
   {
     enter_IDLE_MODE();
     return;    
   }

   /* Escape set mode by long press of dial */
   if( input_dialIsPressed() && input_getCurrentPressDuration()>PRESS_DURATION_SHORT)
   {
        enter_IDLE_MODE();
        return;
   }

  /* ignore irritating edgcase of long press/release of dial */
  if( input_dialGotReleased() && input_getLastPressDuration()>PRESS_DURATION_SHORT)  return;

   /* Abort timer by pressing the button of the timer very long */
   if( input_timerButtonIsPressed(ui_focussed_timer_index)
   && input_getCurrentPressDuration()>PRESS_DURATION_FOR_RESET)
   {
       focussed_timer->disable();
       output_resetSequence(myKitchenTimerList,ui_focussed_timer_index);
       enter_IDLE_MODE();
       return;       
   }
   
   /* Start timer with selected time by short press of timer button or dial */
   if((input_timerButtonGotReleased(ui_focussed_timer_index) || input_dialGotReleased() )&& input_getLastPressDuration()<PRESS_DURATION_SHORT ) 
   {
     if(ui_partner_timer_index==INDEX_FOR_UNDEFINED_TIMER) {  // normal time setting
         focussed_timer->setInterval(convertControlvalueToTime(input_getEncoderValue()));
     } else {             // timesetting relative to other timer
         long relative_target_time= myKitchenTimerList[ui_partner_timer_index].getTimeLeft() - convertControlvalueToTime(input_getEncoderValue());
         if(relative_target_time>1) { // At least 1 second should be left
          focussed_timer->setInterval(relative_target_time);
         } else {  // go back to partner timer if partner timer as not enough time left
     #ifdef TRACE_MAIN_EVENTS
                  Serial.print(F("TRACE_MAIN_EVENTS>Blocking start since partner is smaller "));Serial.print(ui_focussed_timer_index);
     #endif
          output_blockedSequence(myKitchenTimerList,ui_focussed_timer_index);  
          ui_focussed_timer_index=ui_partner_timer_index;
          enter_DISPLAY_MODE();
          return;
         }
     }
     focussed_timer->startCounting();
     #ifdef TRACE_MAIN_EVENTS
                  Serial.print(F("TRACE_MAIN_EVENTS>Start Timer "));Serial.print(ui_focussed_timer_index);
                  Serial.print(F("Interval is "));Serial.println(focussed_timer->getLastStartTime());
     #endif
     output_startTimerSequence(myKitchenTimerList,ui_focussed_timer_index);
     enter_IDLE_MODE();
     return;    
   } 


   /* Button  of other timer */
  for(int other_timer_index=0;other_timer_index<TIMER_COUNT;other_timer_index++)
  {
    if(other_timer_index==ui_focussed_timer_index) continue;
    
    if(input_timerButtonGotPressed(other_timer_index)) {
      if(myKitchenTimerList[other_timer_index].hasAlert()){  // acknowledge alert
        myKitchenTimerList[other_timer_index].acknowledgeAlert(); 
      } else {
        if(myKitchenTimerList[other_timer_index].isOver() ||
           myKitchenTimerList[other_timer_index].isDisabled())  // Other time has no duty
           {
            ui_focussed_timer_index=other_timer_index;
            focussed_timer=&myKitchenTimerList[ui_focussed_timer_index];
            input_IgnoreUntilRelease();
           } else {
            output_blockedSequence(myKitchenTimerList,other_timer_index); 
           }       
       } 
     } 
   }
  

  /* Display the encoder value */
  output_renderSetScene(myKitchenTimerList,convertControlvalueToTime(input_getEncoderValue()),ui_focussed_timer_index,ui_partner_timer_index);

}



/* ******************   Helpers    *************************     
 * *********************************************************
 */

/* 
 * Translate encoder value into seconds and back. This implementes the escalating step size when intervals get higher
 */


long convertControlvalueToTime(long value)
{
/* this is generated with a google sheet, dont ask for explanation */  
if(value==NO_TIME_SELECTION) return NO_TIME_SELECTION;  
if (value<30) return value;  // First step 1 s  
if (value<48) return 30+(value-30)*5; // Until h 2min Step 0,0833333333333333 min
if (value<66) return 120+(value-48)*10; // Until h 5min Step 0,166666666666667 min
if (value<106) return 300+(value-66)*15;  // Until h 15min Step 0,25 min
if (value<136) return 900+(value-106)*30; // Until h 30min Step 0,5 min
if (value<166) return 1800+(value-136)*60;  // Until 1h min Step 1 min
if (value<190) return 3600+(value-166)*300; // Until 3h 0min Step 5 min
if (value<274) return 10800+(value-190)*900;  // Until 24h 0min Step 15 min
if (value<370) return 86400+(value-274)*1800; // Until 48h min Step 30 min
if (value<538) return 172800+(value-370)*3600;  // Until 168h min Step 60 min
return 604800+(value-538)*10800;  // infinity Step 180 min
}

long convertTimeToControlvalue(long totalSeconds)
{
/* this is generated with a google sheet, dont ask for explanation */
if(totalSeconds<30) return totalSeconds;
if(totalSeconds<120) return (totalSeconds-30)/5+30;
if(totalSeconds<300) return (totalSeconds-120)/10+48;
if(totalSeconds<900) return (totalSeconds-300)/15+66;
if(totalSeconds<1800) return (totalSeconds-900)/30+106;
if(totalSeconds<3600) return (totalSeconds-1800)/60+136;
if(totalSeconds<10800) return (totalSeconds-3600)/300+166;
if(totalSeconds<86400) return (totalSeconds-10800)/900+190;
if(totalSeconds<172800) return (totalSeconds-86400)/1800+274;
if(totalSeconds<604800) return (totalSeconds-172800)/3600+370;
return (totalSeconds-604800)/10800+538;
}

 #ifdef TRACE_ON 
void trace_printTime(long timeValue)
{
    Serial.print((timeValue/86400));
    Serial.print(F("d "));
    Serial.print((timeValue/3600)%24);
    Serial.print(F(":"));
    Serial.print((timeValue/60)%60);
    Serial.print(F(":"));
    Serial.print(timeValue%60);  
}
#endif

/* *********************    Main Setup   **********************
 * ************************************************************
 */

void setup() {

  #ifdef TRACE_ON 
    char compile_signature[] = "--- START (Build: " __DATE__ " " __TIME__ ") ---";   
    Serial.begin(9600);
    Serial.println(compile_signature); 
  #endif
  
  pinMode(LED_BUILTIN,OUTPUT);
  digitalWrite(LED_BUILTIN,LOW);   

  sound_setup();
  output_setup();
  input_setup(); 

  input_setEncoderRange(0,1,1,false);


  #ifdef DEBUG_SCALE_TABLE
  /* Test of stepconversion */
  long timevalue;
  long controlvalue;
  
  for(long i=0;i<312;i++) {
    timevalue=convertControlvalueToTime(i);
    controlvalue=convertTimeToControlvalue(timevalue);
    Serial.print(i); 
    Serial.print(F(" - "));
    Serial.print(controlvalue);
    Serial.print(F("\t = "));
    trace_printTime(timevalue);
    Serial.print(F("\t > "));
    trace_printTime(convertControlvalueToTime(controlvalue));
    Serial.println();
  }
  #endif

}

/* ********************    Main Loop     **********************
 * ************************************************************
 */

void loop() {
   /* Inputs */
  input_switches_scan_tick();

    /* UI logic */
    switch (ui_mode) {
          case IDLE_MODE:                 process_IDLE_MODE(); break;
          case PRESELECT_MODE:            process_PRESELECT_MODE(); break;
          case DISPLAY_MODE:              process_DISPLAY_MODE(); break;
          case SET_MODE:                  process_SET_MODE(); break;

    }

  /* Manage sound */
  for(int i=0;i<TIMER_COUNT;i++) {
    if(myKitchenTimerList[i].hasAlert()) {
      sound_playAlarmForTimer(i);
    } else {
      sound_stopAlarmForTimer(i);
    }    
  }
  sound_tick();
}

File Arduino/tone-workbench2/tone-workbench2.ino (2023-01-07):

/*
  Melody

  Plays a melody

  circuit:
  - 8 ohm speaker on digital pin 8

  created 21 Jan 2010
  modified 30 Aug 2011
  by Tom Igoe

  This example code is in the public domain.

  http://www.arduino.cc/en/Tutorial/Tone
*/

#include "mainSettings.h"

#define TRACE_SOUND


#define NOTE_B0  31
#define NOTE_C1  33
#define NOTE_CS1 35
#define NOTE_D1  37
#define NOTE_DS1 39
#define NOTE_E1  41
#define NOTE_F1  44
#define NOTE_FS1 46
#define NOTE_G1  49
#define NOTE_GS1 52
#define NOTE_A1  55
#define NOTE_AS1 58
#define NOTE_B1  62
#define NOTE_C2  65
#define NOTE_CS2 69
#define NOTE_D2  73
#define NOTE_DS2 78
#define NOTE_E2  82
#define NOTE_F2  87
#define NOTE_FS2 93
#define NOTE_G2  98
#define NOTE_GS2 104
#define NOTE_A2  110
#define NOTE_AS2 117
#define NOTE_B2  123
#define NOTE_C3  131
#define NOTE_CS3 139
#define NOTE_D3  147
#define NOTE_DS3 156
#define NOTE_E3  165
#define NOTE_F3  175
#define NOTE_FS3 185
#define NOTE_G3  196
#define NOTE_GS3 208
#define NOTE_A3  220
#define NOTE_AS3 233
#define NOTE_B3  247
#define NOTE_C4  262
#define NOTE_CS4 277
#define NOTE_D4  294
#define NOTE_DS4 311
#define NOTE_E4  330
#define NOTE_F4  349
#define NOTE_FS4 370
#define NOTE_G4  392
#define NOTE_GS4 415
#define NOTE_A4  440
#define NOTE_AS4 466
#define NOTE_B4  494
#define NOTE_C5  523
#define NOTE_CS5 554
#define NOTE_D5  587
#define NOTE_DS5 622
#define NOTE_E5  659
#define NOTE_F5  698
#define NOTE_FS5 740
#define NOTE_G5  784
#define NOTE_GS5 831
#define NOTE_A5  880
#define NOTE_AS5 932
#define NOTE_B5  988
#define NOTE_C6  1047
#define NOTE_CS6 1109
#define NOTE_D6  1175
#define NOTE_DS6 1245
#define NOTE_E6  1319
#define NOTE_F6  1397
#define NOTE_FS6 1480
#define NOTE_G6  1568
#define NOTE_GS6 1661
#define NOTE_A6  1760
#define NOTE_AS6 1865
#define NOTE_B6  1976
#define NOTE_C7  2093
#define NOTE_CS7 2217
#define NOTE_D7  2349
#define NOTE_DS7 2489
#define NOTE_E7  2637
#define NOTE_F7  2794
#define NOTE_FS7 2960
#define NOTE_G7  3136
#define NOTE_GS7 3322
#define NOTE_A7  3520
#define NOTE_AS7 3729
#define NOTE_B7  3951
#define NOTE_C8  4186
#define NOTE_CS8 4435
#define NOTE_D8  4699
#define NOTE_DS8 4978





#define SOUND_OUT_PIN 5
#define TRACE_MONITOR_LED_PIN LED_BUILTIN

// notes in the melody in pairs of normal note and highlight note (will be played on position of alarming timer):
int notes[] = {
  NOTE_B6,NOTE_D7,
   NOTE_A6,NOTE_CS7,
   NOTE_CS7,NOTE_E7
}; 

const byte sound_pattern [] {  // Option for less memory consumption: compress this into 4 bit per note or put it to code 
            1,1,1,1,1,0,0,0,
            1,1,1,1,1,0,0,0,
            3,3,3,3,3,0,0,0,
            3,3,3,3,3,0,0,0,
            5,5,5,5,5,0,0,0,
            5,5,5,5,5,0,0,0,
            1,1,1,1,1,0,0,0,
            1,1,1,1,1,0,0,0
};

#define SOUND_PATTERN_RYTHMGROUP_LENGTH 8

#define SOUND_PATTERN_COUNT sizeof(sound_pattern)/sizeof(sound_pattern[0])
#define NOTE_COUNT sizeof(notes)/sizeof(notes[0])

#define NOTE_DURATION 125
#define PAUSE_DURATION NOTE_DURATION*1.30

byte sound_active_flags=0;
unsigned long sound_last_tick_time=0;

byte sound_current_frame=0;

/*  ************************  interface  ********************************
 *  *********************************************************************
 */

void sound_playAlarmForTimer(byte timer_index)
{

  if(bitRead(sound_active_flags,timer_index)==0) // Sound for this alarm is just triggered
  {
      sound_current_frame=0;
      sound_last_tick_time=0;
      bitSet(sound_active_flags,timer_index);
  }
}

void sound_stopAlarmForTimer(byte timer_index)
{
  bitClear(sound_active_flags,timer_index);
  if(sound_active_flags==0) // this was the last alarm running
  {
    noTone(SOUND_OUT_PIN);
  }
}

void sound_stopAll(byte timer_index)
{
  sound_active_flags=0;
  noTone(SOUND_OUT_PIN);
}

void sound_playTimerStartMelody() {  // Contains a delay of 250 ms
    tone(SOUND_OUT_PIN,NOTE_F6,NOTE_DURATION/2);
    delay(PAUSE_DURATION/2);
    tone(SOUND_OUT_PIN,NOTE_A6,NOTE_DURATION/2);
    delay(PAUSE_DURATION/2);
    noTone(SOUND_OUT_PIN);
}
/* *************************** TICK *************************************
   Must be called every tick of the core loop
   Manages playing the melody in the background 
*/

void sound_tick()
{
  if(sound_active_flags==0) return;

  if(millis()-sound_last_tick_time>PAUSE_DURATION) // this defines the tempo of subsequent notes
  {
    sound_last_tick_time=millis();
    if(sound_pattern[sound_current_frame]>0)
    {
      byte index_in_rythm=sound_current_frame%SOUND_PATTERN_RYTHMGROUP_LENGTH;
      if(index_in_rythm>0 && index_in_rythm<5 && bitRead(sound_active_flags,index_in_rythm-1)==1) tone(SOUND_OUT_PIN, notes[sound_pattern[sound_current_frame]], NOTE_DURATION);
      else tone(SOUND_OUT_PIN, notes[sound_pattern[sound_current_frame]-1], NOTE_DURATION);
      digitalWrite(TRACE_MONITOR_LED_PIN,HIGH);
    } 
    else {
      noTone(SOUND_OUT_PIN);
      digitalWrite(TRACE_MONITOR_LED_PIN,LOW);
    }
    if(++sound_current_frame>=SOUND_PATTERN_COUNT) sound_current_frame=0;
  }
}

/*  ************************  setup  ************************************
 *  *********************************************************************
 */

void sound_setup() {
  pinMode(SOUND_OUT_PIN,OUTPUT);
  digitalWrite(SOUND_OUT_PIN,LOW);   
  #ifdef TRACE_SOUND
  pinMode(TRACE_MONITOR_LED_PIN,OUTPUT);
  digitalWrite(TRACE_MONITOR_LED_PIN,LOW);    
  #endif
}

/* *************************helper main code ************************** */

void setup() {

   #ifdef TRACE_ON 
    char compile_signature[] = "--- START (Build: " __DATE__ " " __TIME__ ") ---";   
    Serial.begin(9600);
    Serial.println(compile_signature); 
  #endif

  input_setup();
   sound_setup();
   pinMode(LED_BUILTIN,OUTPUT);
  sound_playTimerStartMelody();
}

void loop() {

 sound_tick();
 input_switches_scan_tick();
 if(input_dialGotPressed())   sound_stopAll(0);
 for(byte t=0;t<4;t++)   {
   if(input_timerButtonGotPressed(t)) sound_playAlarmForTimer(t);
   }

 }

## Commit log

2018-08-02 Implemented basic framework
2018-08-02 added timer class, safety commit for first output features
2018-08-02 Output of compact timer works (except for alarm display)
2018-08-02 Led blinks correct according to timer status
    [kitchenTimer.cpp, output.ino]
2018-08-03 Set mode nearly done as first prototype
2018-08-03 Set mode works properly (with prototyp Button handling)
2018-08-03 Main change: get signle button presses from the module
2018-08-03 Hold function now on select button, default start values when start settin an overdue timer depends on direction, wich initiates the change (- = 0. += 10min)
2018-08-04 refactoring of input complete, refactoring of kitchen timer states nearly done (leds dont show any more)
2018-08-04 Leds working againt
2018-08-04 Tested setting of dots, corrected hold feature
    [board_handling_workbench.ino]
2018-08-04 Manages multiple timers perfectly
2018-08-04 disabling timer (first version implemented)
2018-08-04 Change of reset operation, added display of start interval
    [input.ino, kitchenTimer.cpp, output.ino]
2018-08-05 Integrated encoder, added encoder acceleration
2018-08-05 Added Fristzing with current layout
    [ElbanquosKitchentimer_MK1.fzz]
2018-08-06 Added Preselection Mode, Changed Presets, Bugfix: Long time display over 24 hours was wrong
    [output.ino]
2018-08-06 Added "calm down" display for timers that are over
2018-08-06 bugfix: prevent encode change during pressing encoder
    [input.ino]
2018-08-07 Added 3D Animation with housing idea
    [model_mk2.blend]
2018-08-07 refectored core: introduced display mode instaed of tracking "Timer update flag". Feature: Instant timer start from presection. "Go" Animation at start.
2018-08-07 LED intensity lower, Bugfix: bad default when start selection from "over" timer
    [output.ino]
2018-08-11 Updated fritzing schema to nano and small breadboard design
    [ElbanquosKitchentimer_MK1.fzz]
2018-08-11 Added the missing capacitor
    [ElbanquosKitchentimer_MK1.fzz]
2018-08-12 Create manual-de,md
2018-08-28 Red green LED POC
2018-09-13 mk2 Steckplatine Entwurf
    [ElbanquosKitchentimer_MK2.fzz]
2018-09-13 Schaltplan komplett
    [ElbanquosKitchentimer_MK2.fzz]
2018-09-14 Platinenlayout fertig
    [ElbanquosKitchentimer_MK2.fzz]
2018-09-20 Modified pins for Display when putting on breadboard
    [ElbanquosKitchentimer_MK2.fzz]
2018-09-21 Reworked input to MK2 Architecture
    [input.ino, led_and_button_workbench.ino, output.ino]
2018-09-23 led and button workbench works fine. Added MK2 Project.
2018-09-23 Presstime get measured correctly
    [input.ino, led_and_button_workbench.ino]
2018-09-23 updated fritzing/ElbanquosKitchentimer_MK2.fzz to current state
    [ElbanquosKitchentimer_MK2.fzz]
2018-09-26 Modified circuit to current setting and modularization
    [ElbanquosKitchentimer_MK2.fzz]
2018-09-26 Circuit diagram updated
    [ElbanquosKitchentimer_MK2.fzz]
2018-09-26 Instant response of button led in Of and Go sequence
2018-09-26 Fixed LED13 Alert indicaion, extended alert to 45 seconds, complet disabling timer after 45 Seconds + runtime of timer
    [ElBanquos_Kitchentimer_MK2.ino, sound.ino]
2018-09-26 Long hold deletes timer from idle mode, fixed colors of over timer in set mode
    [ElBanquos_Kitchentimer_MK2.ino, output.ino]
2018-09-27 pcb layout complete
    [ElbanquosKitchentimer_MK2.fzz]
2018-09-30 Pin change
    [ElbanquosKitchentimer_MK2.fzz]
2018-09-30 compiles after input rework
    [input.ino]
2018-09-30 LED and button workbench refactoring complete
2018-09-30 Refactoring encoder input to change interrupt isr complete. sound works now
2018-10-03 Layout for experimental PCB complete
    [ElbanquosKitchentimer_MK2.fzz]
2018-10-07 turned led display upside down
2018-10-07 Rotated led in the circuit (optimized pin usage for easy routing)
    [ElbanquosKitchentimer_MK2.fzz]
2018-10-07 Final speaker Circuit
    [ElbanquosKitchentimer_MK2.fzz]
2018-10-14 Prototype circuit completed
    [ElbanquosKitchentimer_MK2.fzz]
2019-09-22 Bugfix; Issue +1: "A" Indicator now gets removed when releasing selection button
    [ElBanquos_Kitchentimer_MK2.ino]
2020-08-24 Fixed Bug #2 Added display of build time on startup
    [ElBanquos_Kitchentimer_MK2.ino, output.ino]
2023-01-05 refactored encoder reading to "single interrupt on clock pin" pattern
2023-01-05 some refactoring for better readbility of the code
    [ElbanquosKitchentimer_MK2.fzz]
2023-01-06 Added related timer setting to manual de
2023-01-06 Prototyped new melody concept
